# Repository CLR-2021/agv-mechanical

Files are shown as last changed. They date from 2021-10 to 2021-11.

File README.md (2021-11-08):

<p align="center">
  
</p>
<h1 align="center">AGV</h1>

---
## MECHANICAL progress
SW tools used: [SolidWorks SolidWorks](https://www.solidworks.com/)

***Responsibilities***
   * 3D design.
   * Analysis.
   * Mechanisms. 
   * Manufacturing.
   * etc.

***Progress***: can be found in file [mechanicalTasks.xlsx](https://github.com/CLR-2021/agv-mechanical/blob/master/mechanicalTasks.xlsx)

*Featured image:*

<p align="center">
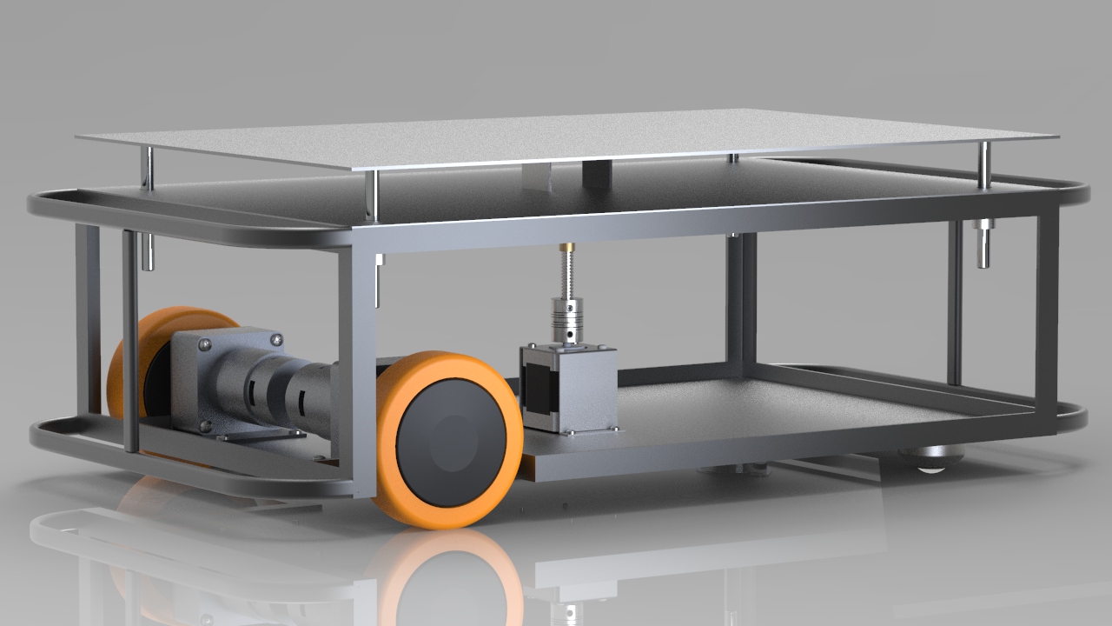
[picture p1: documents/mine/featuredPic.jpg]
featuredPic
  
</p>

---
## All Project
For detailed information about: 
* Vision
* Team Hierarchy
* Future Work
* Working of other technical teams  
* Licenses of the project
* Sponsorship

Check this readme page for detailed information about the project: [agv-documents](https://github.com/CLR-2021/agv-documents)

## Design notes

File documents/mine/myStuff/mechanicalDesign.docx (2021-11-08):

Mechanical Design

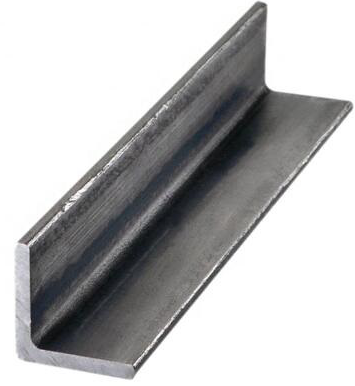
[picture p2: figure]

Chassis Design:

Design the robot body chassis with steel structure to withstand heavy loads with regardless deformation. L steel profile (Equal angle 15mm width, 3mm thickness) is suitable for the robot because it is the smallest member in the market, which means lowest weight, and it gives the best results using Solidworks software simulation.

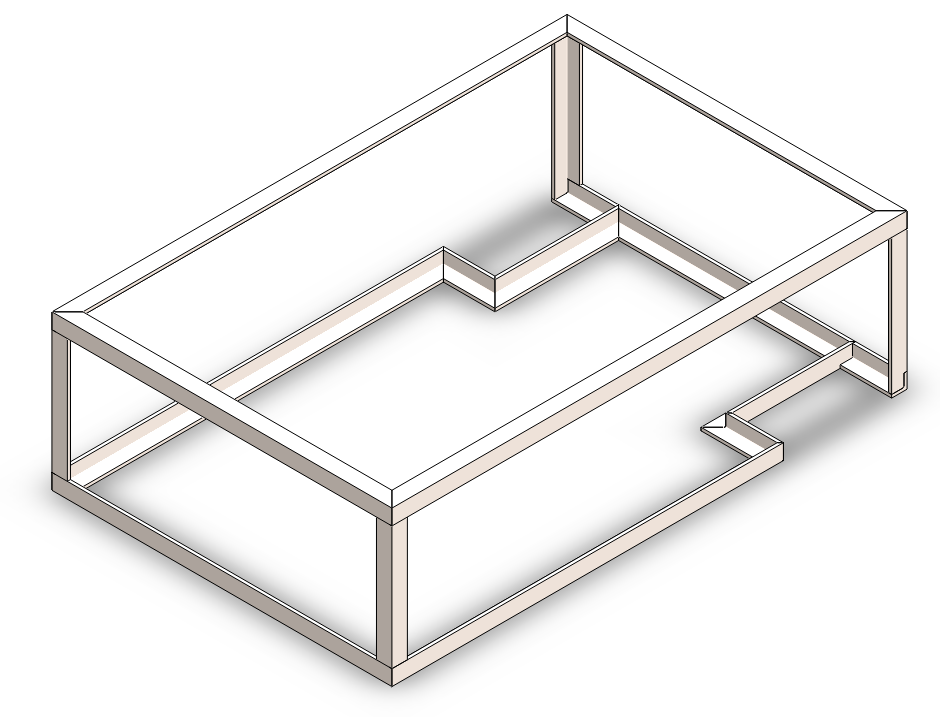
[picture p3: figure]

The drawings of the steel structure:

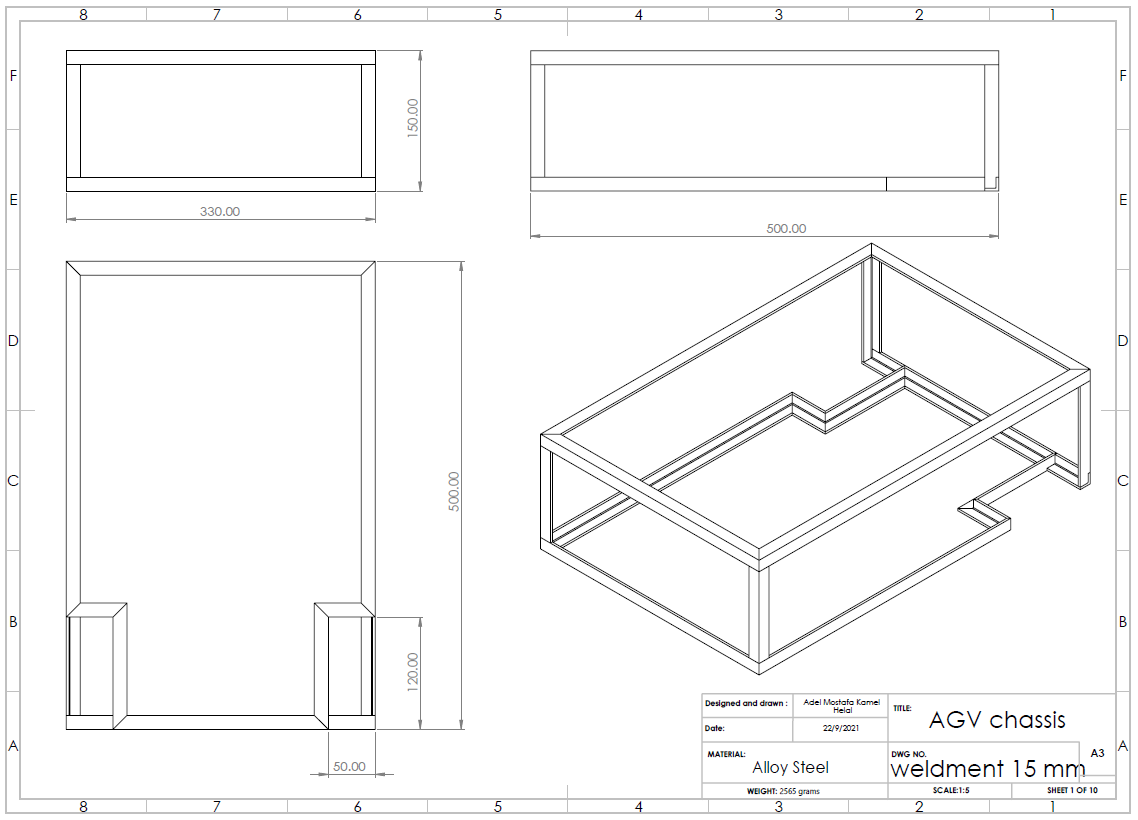
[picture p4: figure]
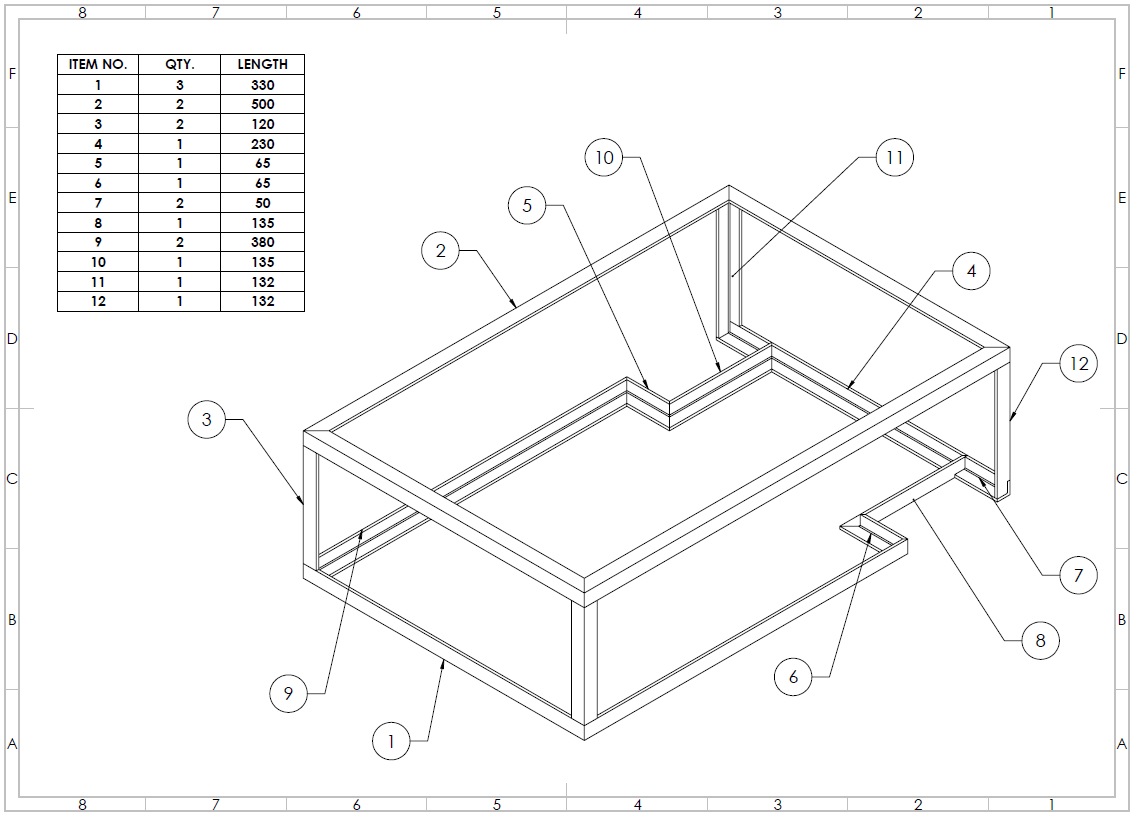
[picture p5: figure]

The simulation results using Solidworks CAD software:

With the full load the simulations results shows that the maximum resulted yield strenght equal 3.138 e+08 N/m^2, where the yeild strength of the steel is 6.204 e+08 N/m^2 which means that there is no temporary deformation of the stucture even it is a small deformation (0.11 e-1 mm).

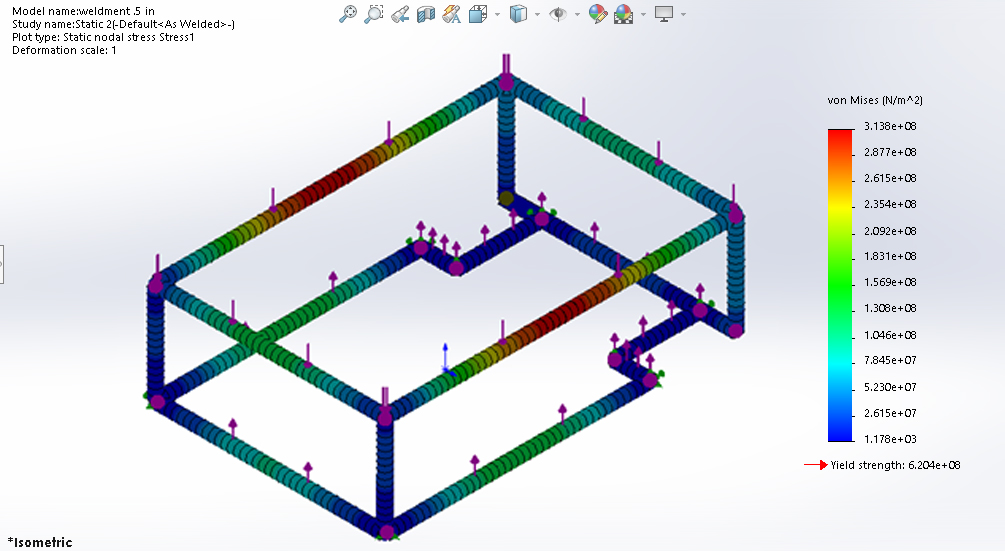
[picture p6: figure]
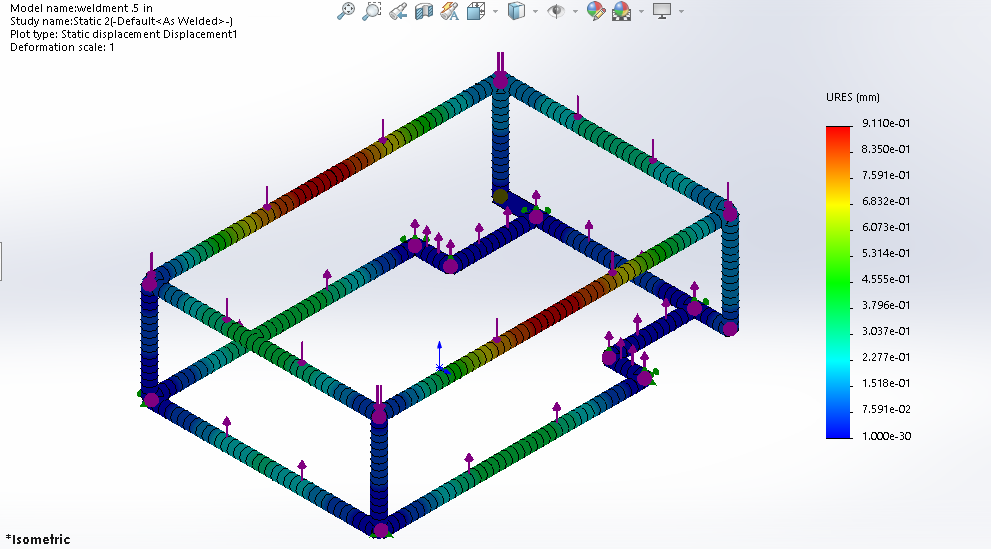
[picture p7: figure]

The simulation of 1 mm sheet metal:

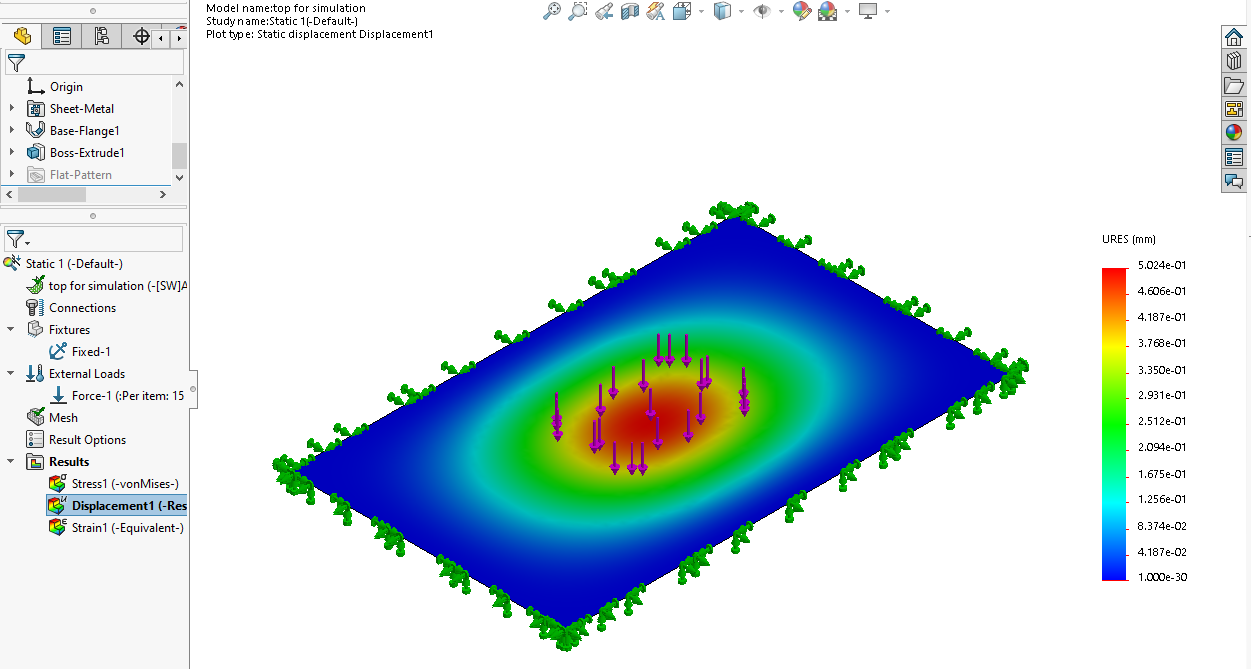
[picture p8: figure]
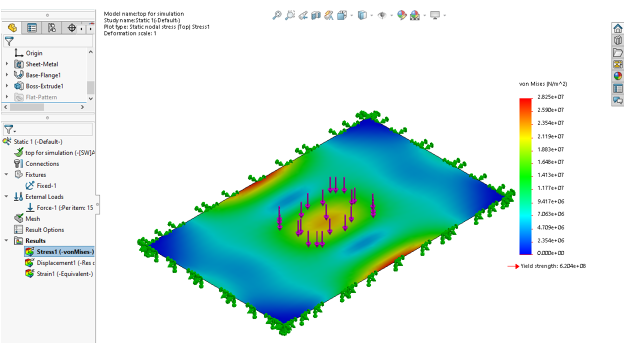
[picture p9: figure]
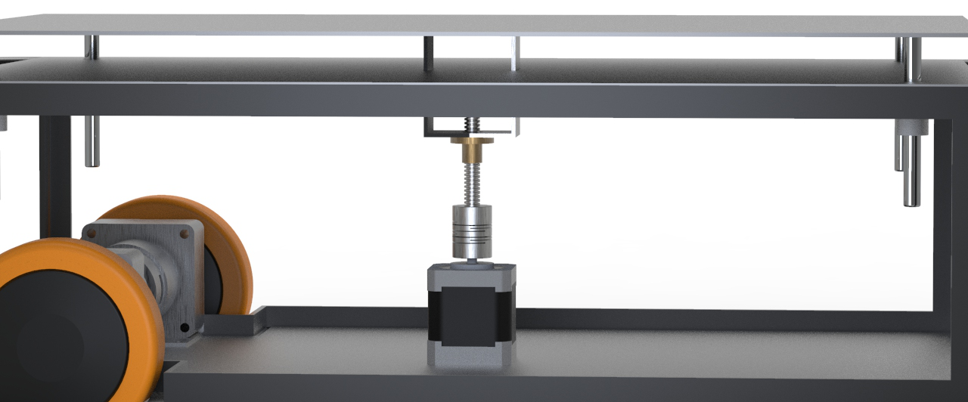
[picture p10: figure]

Lifter Mechanism:

For the lifter mechanism we use Lead Screw mechanism to make linear actuator driven by a stepper motor.

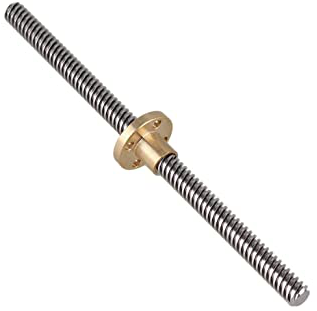
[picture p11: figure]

- Lead screws are self-locking (they stay where they are with no need for braking mechanism). In addition to low cost, this make them the best solution.

Lead screw: Stainless Square threaded Lead Screw with single start thread and outer diameter of 8 mm.

Stepper motor: The calculations for the torque required to derive the Lead screw is given by the equation:

T=(Fd_m)/2[(l + πμd_m secα)/(πd_m - μlsecα)]

Where:

F → Weight force applied

μ → Coefficient of friction

d_m → Mean diameter

l → Lead

α → Tread angle

For our project the force applied will be the weight of the load which is assumed to be

F = 15 kg- force, and the other specifications are constant relative to the selected lead screw which are:

μ = 0.15, d_m = 7 mm, l = 2 mm, α = 14.5^(°)

T=((15*9.81)*0.007)/2[(.002 + π*.015*.007sec14.5^(°))/(π*0.007 - 0.15*0.002sec14.5^(°))]

T=0.128 N.m

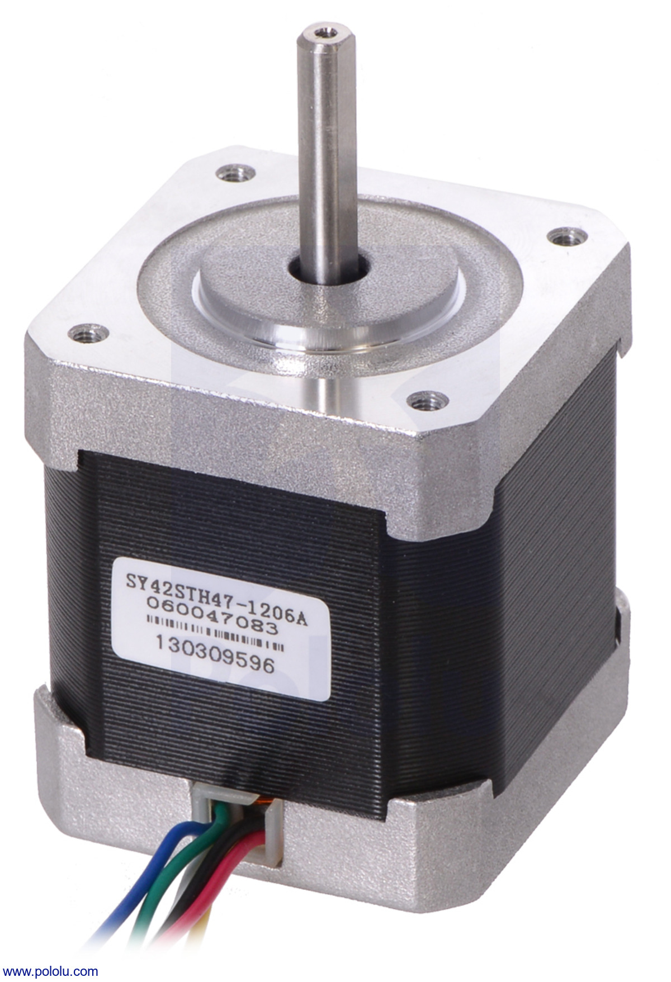
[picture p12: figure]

NEMA 17 stepper motor is suitable for this mechanism because it gives maximum torque of 0.42 N.m which is greater than the required torque.

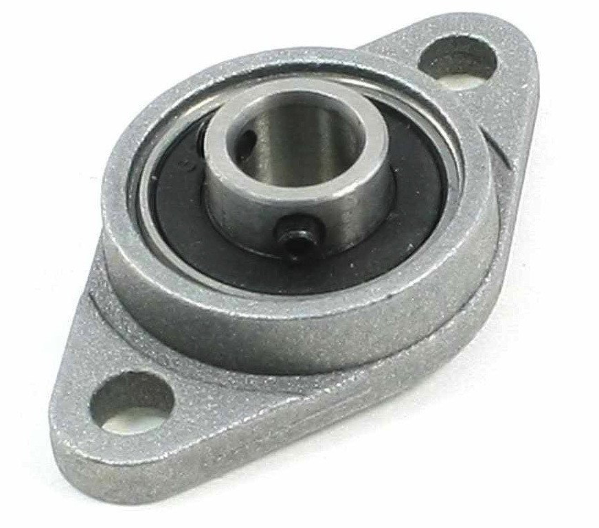
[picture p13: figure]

Pillow bearing: The KFL08 bearing is designed to provide shaft support where the mounting surface is perpendicular (vertical axis) to the shaft axis.

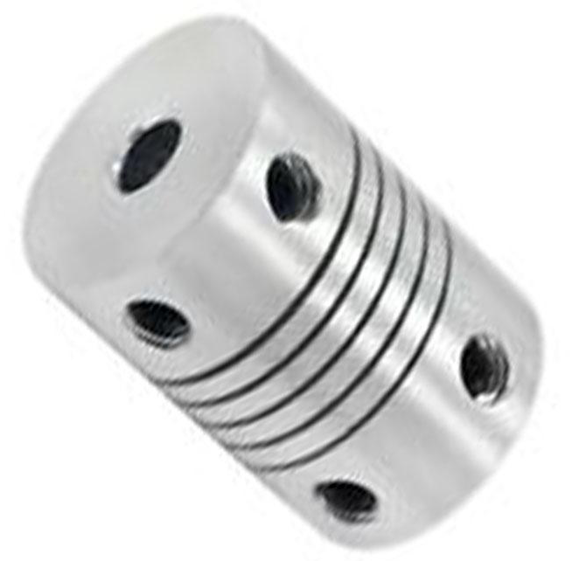
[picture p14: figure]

Coupling: Connect the stepper motor shaft (5 mm) to the screw (8 mm) with a set-screw coupler. These couplers are made of machined aluminum and have a spiral cut that makes them slightly flexible so they can be fit to two shafts even if they are not perfectly co-linear and will help reduce bending effects.

Linear Bearing.

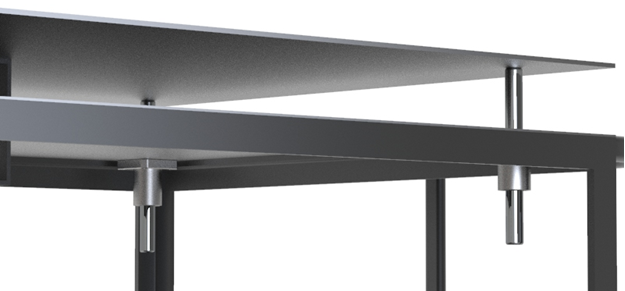
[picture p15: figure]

For the lifting sheet, it must be

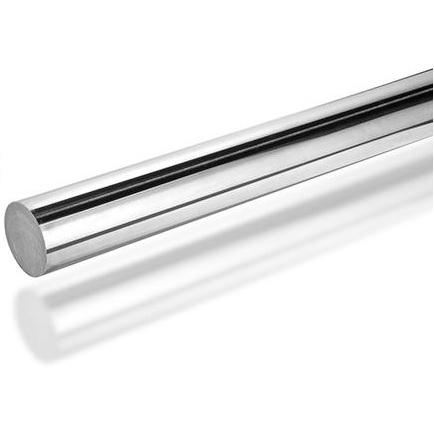
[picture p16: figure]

The chrome plated steel bar is used in conditions of high stress, friction and harsh conditions. Accordingly, the quality of the base metal and subsequent surface treatment are of paramount importance. Wear resistance, corrosion resistance, surface smoothness, high yield strength and uniform quality are essential properties of chrome plated bars.

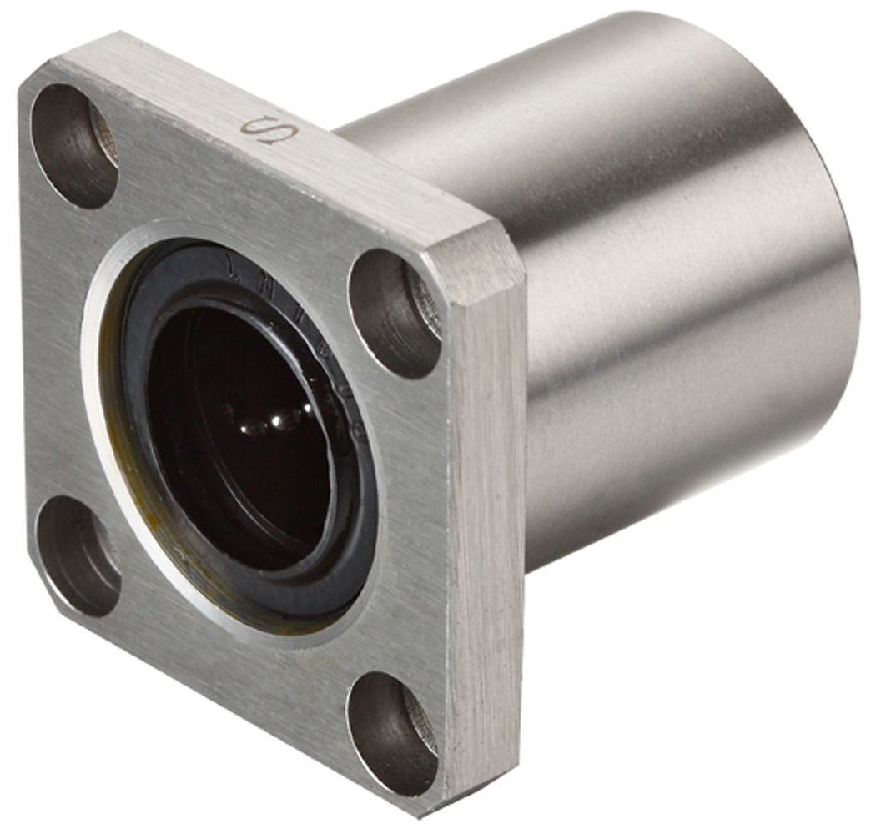
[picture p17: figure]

Flange Mounted Linear Bearing LMK8UU (8mm Diameter). Flange Mount Linear Recirculating Ball Bearings offer the same great advantages of the standard recirculating linear Ball Bearings and they also incorporate a perpendicular flange for easy mounting.

DC Motor fixture:

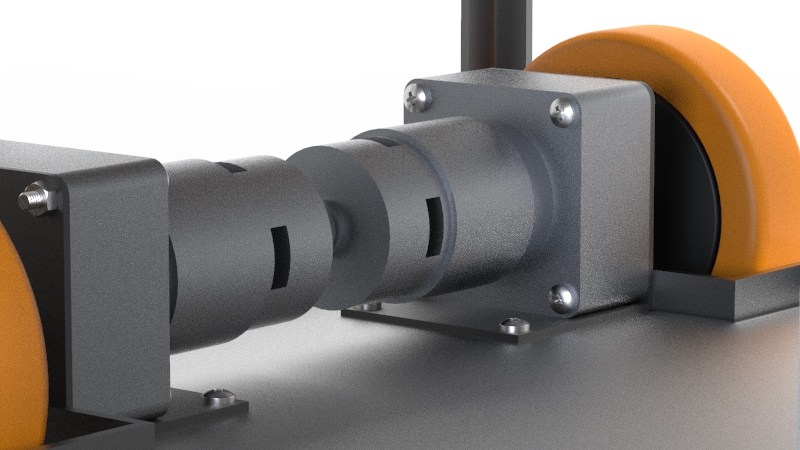
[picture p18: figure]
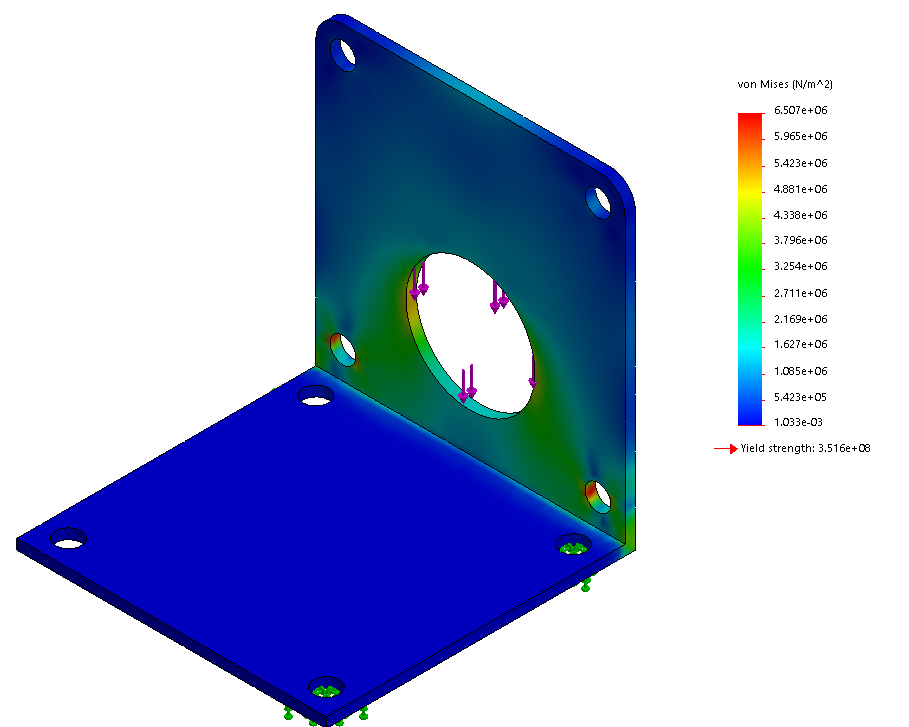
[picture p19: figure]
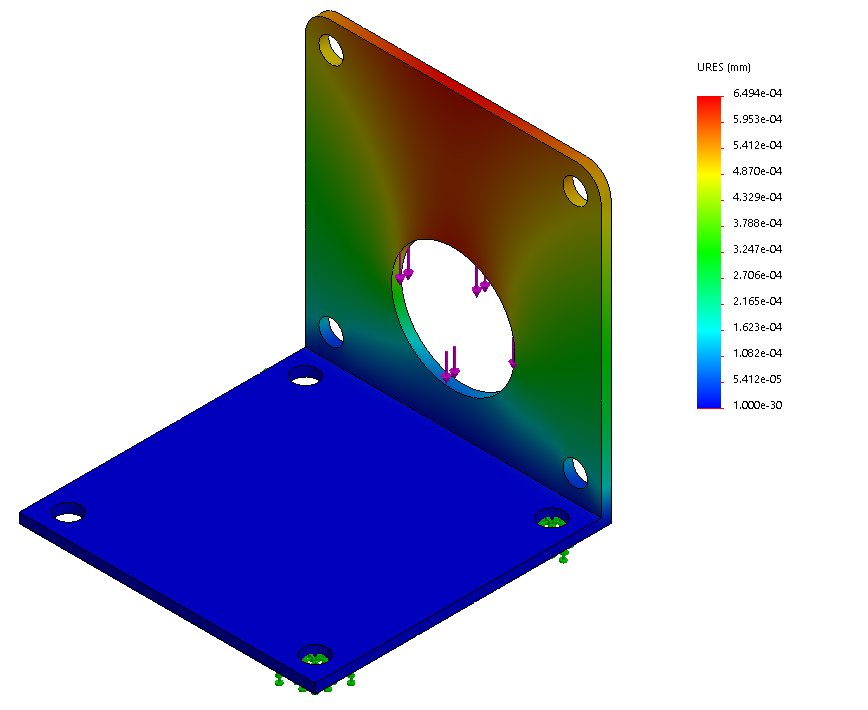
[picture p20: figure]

Stepper motor fixture:

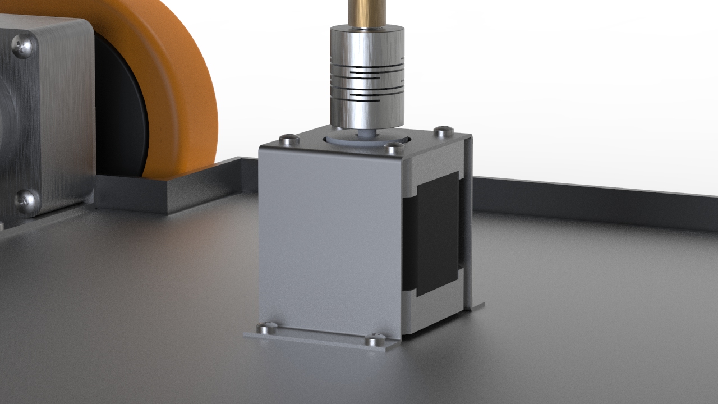
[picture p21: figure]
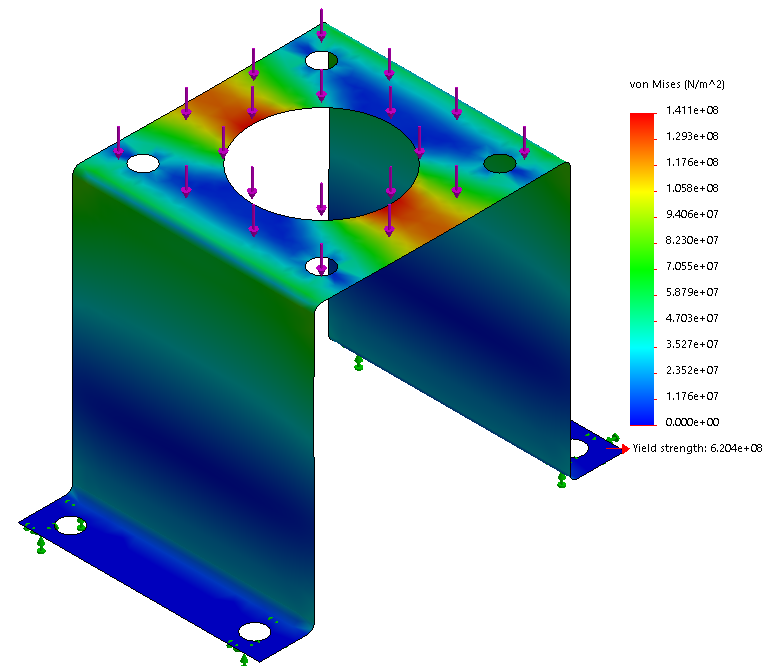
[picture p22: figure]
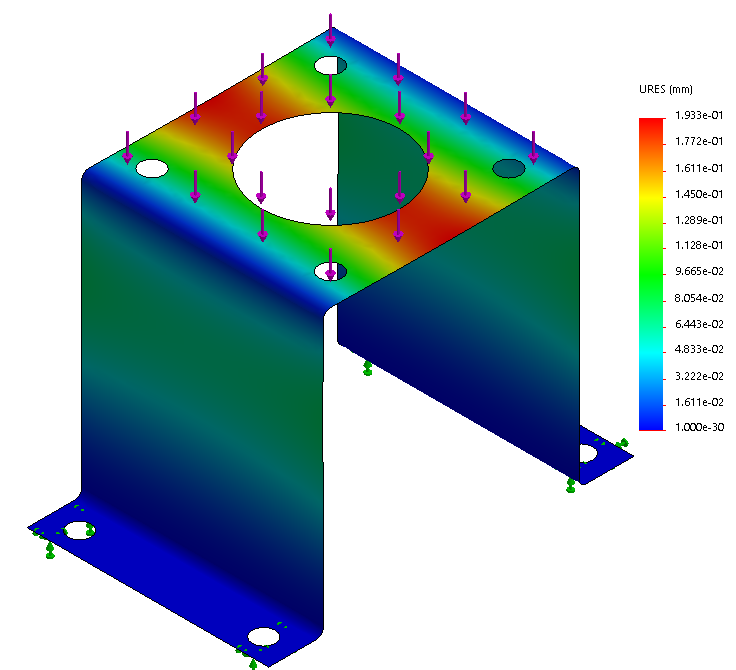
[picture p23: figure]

Motor coupler lathe:

The motor shaft is 8 mm diameter and the wheel bore is 20 mm diameter. To connect them together we have to fabricate a custom coupling.

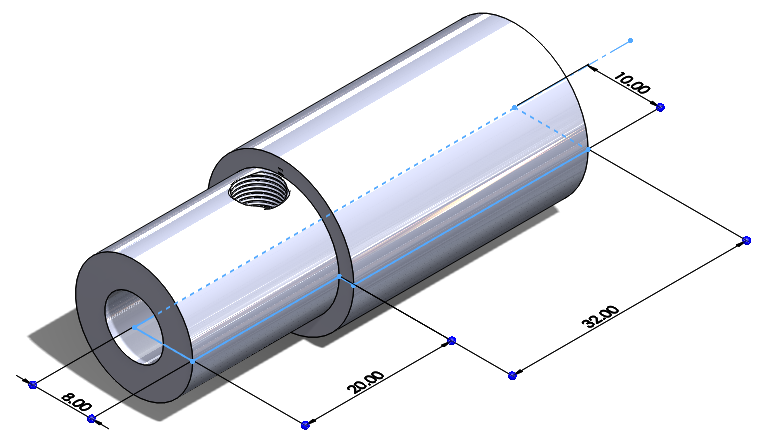
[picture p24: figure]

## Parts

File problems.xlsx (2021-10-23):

No. | Description | Solution | Status
1 |  |  | Solved
2 |  |  | Solved
3 |  |  | Solved
4 |  |  | Solved
5 |  |  | In Progress
6 |  |  | Unsolved
7
8
9
10
11
12
13
14
15
16
17
18
19
20
21
22

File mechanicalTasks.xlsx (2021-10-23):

For Sorting, Select All (Ctrl + A), then press Ctrl + Alt + L
Next ToDo: * Give the robot coordinates to navigate * Connect with NRF to get coordinates from the master PC * Integrate Labview
No. | Feature | Status | Priority | Comment
1 |  | In Progress | High
3 |  | To Do | High
4 |  | To Do | High
5 |  | To Do | High
6 |  | To Do | High
7 |  | To Do | Medium
8 |  | To Do | Medium
9 |  | To Do | Medium
10 |  | To Do | Low
11 |  | Done | High
12 |  | Done | High
13 |  | Done | High
14 |  | Done | High
15
16
17
18
19
20
21
22
23
24

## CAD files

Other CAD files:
documents/mine/sensorsPlacementForTurning.SLDPRT

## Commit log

2021-10-23 Tasks & Problems files added
    [mechanicalTasks.xlsx, problems.xlsx]
2021-10-23 Documents added
    [sensorsPlacementForTurning.SLDPRT]
